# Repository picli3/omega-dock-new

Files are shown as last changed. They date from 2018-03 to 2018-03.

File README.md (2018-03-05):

# Omega dock\new con rele de estado solido a 220v @ 1A

Project released under CC-BY-SA 4.0 license  


layout 1

1. [Project status](#project-status)  
1. [Project description](#project-description)  
1. [BOM](#bom)  
1. [Photos](#photos) 

If you want to discuss the project, join [the thread in the onion community forum](https://community.onion.io/topic/2284/my-omega-2-2-dock-new)

## Project status
v0.9 tested, working with some bodges  
v1.0 boards not tested yet, **proceed at your own risk**

## Project description 
This is my dock\new project: it's a small dock (same size as the mini dock and the omega) for the Onion Omega 2 and 2+.

I needed the smallest dock i could do, that featured:

* Ethernet
* Type A USB host
* Micro USB for power

It has an onboard linear voltage regulation (i didn't bother going with a switching one for such low power), magnetics integrated in the RJ45 connector to save space, USB host ESD protection (diode array), USB host PTC fuse.

On the left side there is the RJ45 connector and nothing on the back side of the board, so that you can easily access the MicroSD card on the Omega 2+.
On the right side (the antenna side of the omega) you have the USB type A connector, facing outwards, and the microusb connector for power, facing inwards.

The first version, v0.9, had some issues with the ethernet. Currently i've released v1.0 that solves all the issues, adds a led to check power and, making a better use of the space, the RJ45 connector doesn't protrude anymore. I haven't ordered the v1.0 PCBs yet, but the circuit is tested.

I've chosen 0805 passives, 1206 ptc fuse, big smd electrolitic caps, a SOT223 (the classic 1117) for power regulation and a SOT23-6 for usb host protection, so it can all be easily handsoldered with just a plain soldering iron. Probably the hardest part to handsolder is the SOT23-6 but it's easily doable by hand.

The components and board cost for the prototype it's arround 10 to 15€ per board.

## BOM
| Symbol | Package | Quantity | Valore | Note |
|:---:|:---:|:---:|:---:|:---:|
| C1 | CP_Elec_4x5.3 | 1 | 10uF | 10V or higher |
| C2 | CP_Elec_6.3x5.3 | 1 | 100uF | 10V or higher |
| C3, C4 | 0805 | 2 | 100nF | |
| C5 | 0805 | 1 | 1uF | |
| D1 | 1206 | 1 | PWR | Amber LED |
| F1 | 1206 | 1 | 1.5A | PTC Fuse |
| J1 | USB_A | 1 | USB_A | MOLEX 67643-3910 |
| J2 | USB_Micro-B | 1 | USB_PWR | ADAM TECH MCR-AB1-S-RA-SMT-CS1-TR |
| J3 | RJ45_TRAFO_AMPHENOL | 1 | RJ45-TRAFO  | AMPHENOL LMJ1598824110DT39 |
| R1,R2,R3,R4 | 0805 | 4 | 50R | Ethernet termination resistors: should be 1% or better |
| R5 | 0805 | 1 | 150R | |
| U1 | SOT23-6 | 1 | USBLC6-2SC6 | |
| U2 | SOT223 | 1 | AP111733 | |
| U3 | Socket_Strip_Straight_1x16_Pitch2.00mm | 2 | OMEGA_2_2+  | Two 2mm 1x16 strip connectors |

## Photos





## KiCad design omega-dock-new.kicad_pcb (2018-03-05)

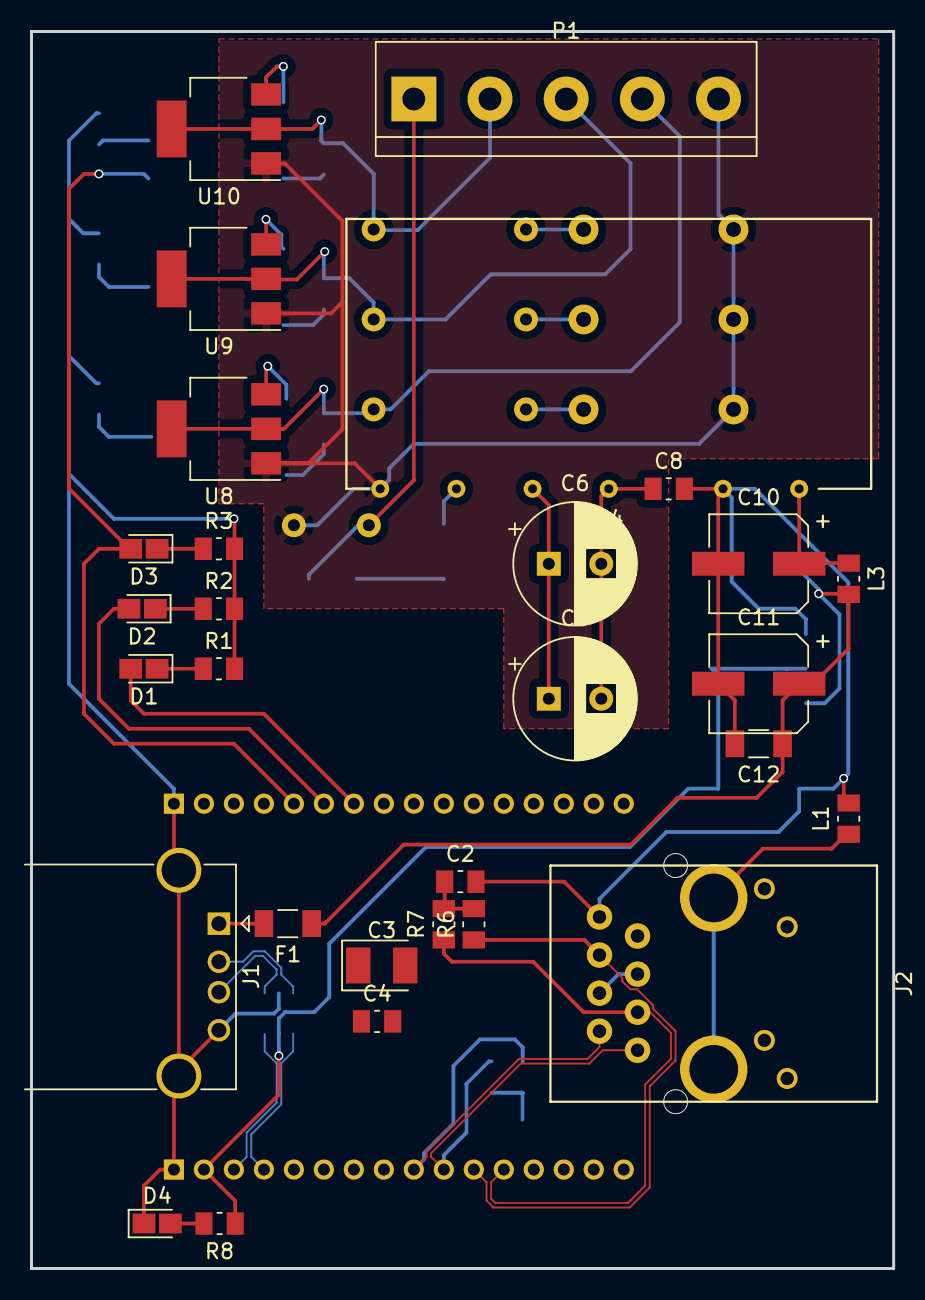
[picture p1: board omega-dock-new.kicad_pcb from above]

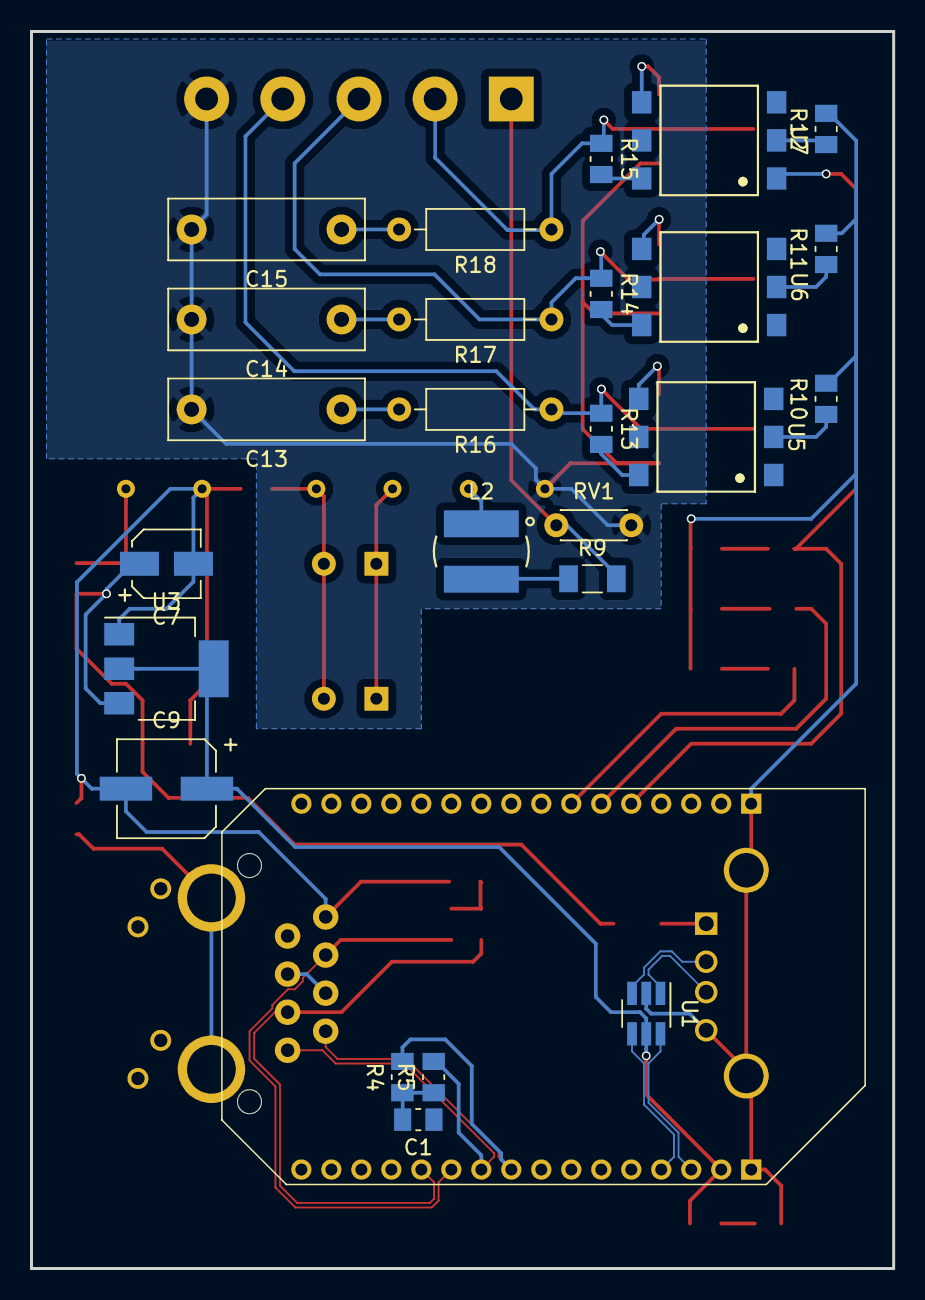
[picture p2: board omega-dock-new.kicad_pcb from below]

Board: 2 copper layers, 57.5 x 82.5 mm, 55 parts (26 on the bottom side), 45 nets.

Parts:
C1, C2: 100nF; C_0805_2012Metric_Pad1.15x1.50mm_HandSolder
C3: 47uF; CP_EIA-3528-12_Kemet-T_Pad1.63x2.40mm_HandSolder
C4, C8: 1nF; C_0805_2012Metric_Pad1.15x1.50mm_HandSolder
C5, C6: 4,7uF; CP_Radial_D8.0mm_P3.50mm
C7: 10uF; CP_Elec_4x5.3
C9: 100uF; CP_Elec_6.3x5.3
C10: 270uF; CP_Elec_6.3x7.7
C11: 68uF; CP_Elec_6.3x7.7
C12: 100nF; C_1206_3216Metric_Pad1.24x1.80mm_HandSolder
C13, C14, C15: 1nF; C_Rect_L13.0mm_W4.0mm_P10.00mm_FKS3_FKP3_MKS4
D1, D2, D3: LED; LED_0805_2012Metric_Castellated
D4: PWR; LED_0805_2012Metric_Castellated
F1: 1.5A; C_1206_3216Metric_Pad1.24x1.80mm_HandSolder
J1: USB_A; USB_A_Horizontal
J2: RJMG1BD3B8K1ANR; RJMG1B
L1: 220@100MHz; L_0805_2012Metric_Pad1.15x1.50mm_HandSolder
L2: SDR0503-472JL; SDR0503-XXX
L3: 74479776247; L_0805_2012Metric_Pad1.15x1.50mm_HandSolder
P1: POWER I/O; TerminalBlock_bornier-5_P5.08mm
R1, R2, R3: 220; R_0805_2012Metric_Pad1.15x1.50mm_HandSolder
R4, R5, R6, R7: 50R; R_0805_2012Metric_Pad1.15x1.50mm_HandSolder
R8: 150R; R_0805_2012Metric_Pad1.15x1.50mm_HandSolder
R9: 300k; R_1206_3216Metric_Pad1.24x1.80mm_HandSolder
R10, R11, R12, R13, R14, R15: 330; R_0805_2012Metric_Pad1.15x1.50mm_HandSolder
R16, R18: 33; R_Axial_DIN0207_L6.3mm_D2.5mm_P10.16mm_Horizontal
R17: 100; R_Axial_DIN0207_L6.3mm_D2.5mm_P10.16mm_Horizontal
RV1: B72214S0351K101; C_Disc_D4.3mm_W1.9mm_P5.00mm
U1: USBLC6-2; SOT-23-6_Handsoldering
U2: OMEGA_2
U3: AP111733; SOT-223
U4: PBO-3-S5
U5, U6, U7: MOC3063S-TA1; MOC306X
U8, U9, U10: Z0103MN 5AA4; SOT-223-Z01

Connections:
+3V3: C9.1, R8.1, U1.5, U2.31, U3.2, U3.4
+5V: C7.1, C11.1, C12.1, F1.1, L3.2, U3.3
/D+: U1.6, U2.30
/D-: U1.4, U2.29
/FuenteST/VO: C10.1, L3.1, U4.12
/OutTriac/Compresor: D3.2, U2.5, U7.1
/OutTriac/Resistencia: D1.2, U2.7, U6.1
/OutTriac/Ventilador: D2.2, U2.6, U5.1
/RX+: J2.3, R7.1, U2.21
/RX-: J2.6, R6.1, U2.22
/TX+: J2.1, R5.2, U2.23
/TX-: J2.2, R4.2, U2.24
/UD+: J1.3, U1.1
/UD-: J1.2, U1.3
CO: P1.2, R15.1, R18.1, U10.2
ETH_PWR: C3.1, C4.1, J2.4, J2.5, U2.25
GND: C1.1, C2.2, C3.2, C4.2, C7.2, C8.2, C9.2, C10.2, C11.2, C12.2, D4.1, J1.4, J1.5, J2.8, L1.2, R1.2, R2.2, R3.2, R10.2, R11.2, R12.2, U1.2, U2.1, U2.32, U3.1, U4.10
GNDREF: J2.SH, L1.1
Nac: C13.2, C14.2, C15.2, P1.5, RV1.2, U4.1, U8.1, U9.1, U10.1
unnamed: C1.2, R4.1, R5.1
unnamed: C2.1, R6.2, R7.2
unnamed: C5.1, C6.1, U4.5
unnamed: C5.2, C6.2, C8.1, U4.7
unnamed: C13.1, R16.2
unnamed: C14.1, R17.2
unnamed: C15.1, R18.2
unnamed: D1.1, R1.1
unnamed: D2.1, R2.1
unnamed: D3.1, R3.1
unnamed: D4.2, R8.2
unnamed: F1.2, J1.1
unnamed: L2.1, R9.1
unnamed: L2.2, U4.3
unnamed: R10.1, U5.2
unnamed: R11.1, U6.2
unnamed: R12.1, U7.2
unnamed: R13.2, U5.6
unnamed: R14.2, U6.6
unnamed: R15.2, U7.6
unnamed: U5.4, U8.3
unnamed: U6.4, U9.3
unnamed: U7.4, U10.3
RE: P1.3, R14.1, R17.1, U9.2
VE: P1.4, R13.1, R16.1, U8.2
Vac: P1.1, R9.2, RV1.1

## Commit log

2018-03-03 ajustando a kicad 5
    [omega-dock-new-2018-03-03-15-40-50.sch, omega-dock-new.sch]
2018-03-03 redimencioando unas cosas
    [omega-dock-new.kicad_pcb, omega-dock-new.sch]
2018-03-05 actualizando todos los perifericos
    [FuenteST.sch, OutTriac.sch, omega-dock-new.kicad_pcb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]

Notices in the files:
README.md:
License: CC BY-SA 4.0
